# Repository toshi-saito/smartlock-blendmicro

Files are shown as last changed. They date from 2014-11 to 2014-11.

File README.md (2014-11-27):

# SmartLock by Blend Micro

"SmartLock" implementation for Blend Micro (Arduino Compatible Board)

## iOS Client
https://github.com/toshi-saito/smartlock-ios-client

## Schematic
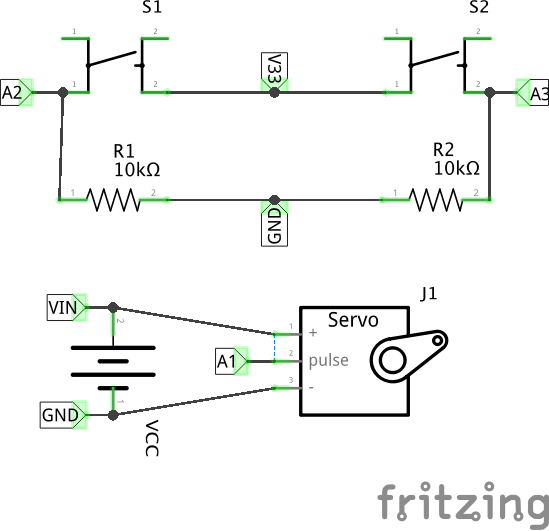
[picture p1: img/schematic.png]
回路図


## Finished product

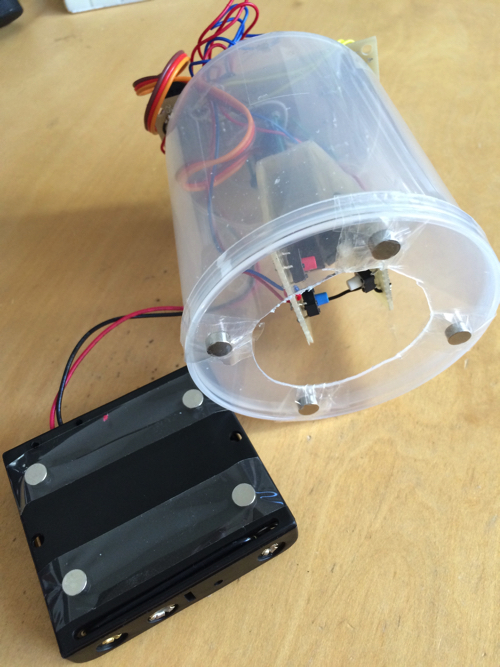
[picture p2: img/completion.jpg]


mounting:  
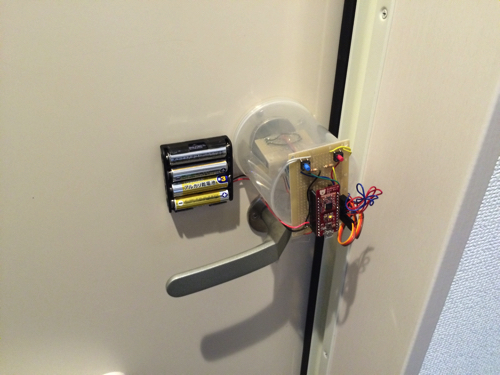
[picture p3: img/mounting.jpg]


front:  
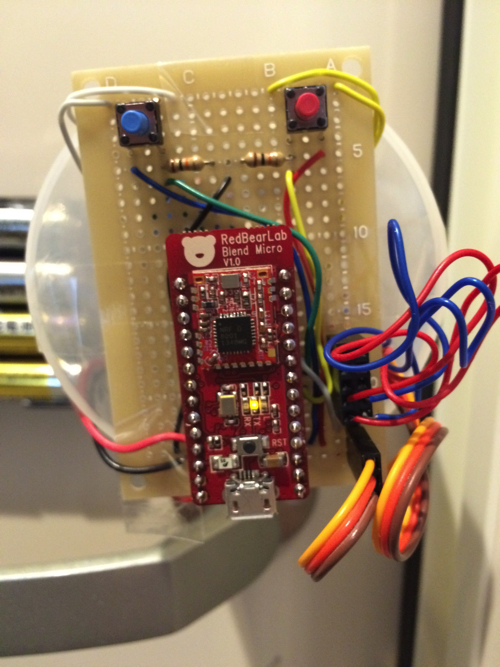
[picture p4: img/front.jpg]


side:  
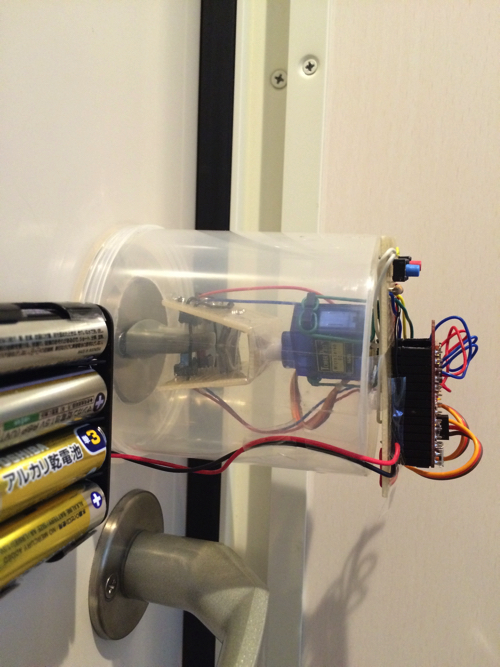
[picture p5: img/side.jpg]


main board side:  
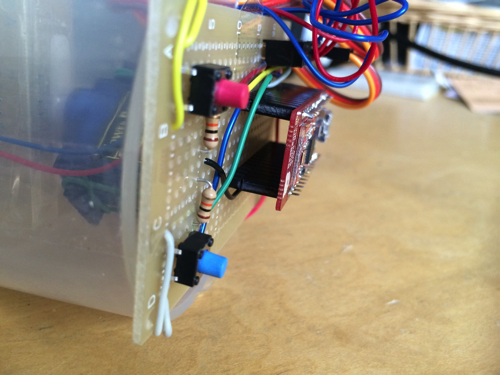
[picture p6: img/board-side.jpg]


thumbturn:  
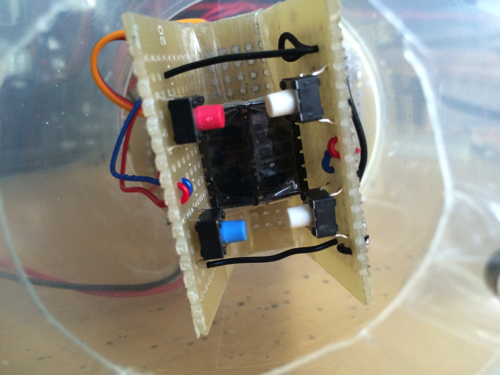
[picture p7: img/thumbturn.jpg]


## Videos
Arduino互換ボードBlendMicroでスマートロックを自作してみた。 (http://www.youtube.com/watch?v=r_P2eok-eCo)

Arduino互換ボードBlendMicroでスマートロックを自作してみた。その2 (http://www.youtube.com/watch?v=pR7_fCwM83g)

## Things to prepare
[Blend Micro](http://redbearlab.com/blendmicro/)  
[カーボン抵抗 carbon resistance 10kΩ ](http://akizukidenshi.com/catalog/g/gR-25103/) x 2  
[タクトスイッチ tact switch](http://akizukidenshi.com/catalog/g/gP-03647/) x 6  
[電池ボックス 単３×４本 4xAA battery box ](http://akizukidenshi.com/catalog/g/gP-02671/) x 1  
[ユニバーサル基板 universal board ](http://akizukidenshi.com/catalog/g/gP-03229/) x 2  
[耐熱電子ワイヤー Heat-resistant electronic wire](http://akizukidenshi.com/catalog/g/gP-06756/)  
[分割ロングピンソケット pin receptacle](http://akizukidenshi.com/catalog/g/gC-05779/)  
[ピンヘッダ pin header](http://akizukidenshi.com/catalog/g/gC-00167/)  
-[サーボモータ servo SG90](http://www.amazon.co.jp/gp/product/B00I9SYEKC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)  
-綿棒ケース swab container x 1 （ダイソーで。）  
-ネオジム磁石 neodymium magnets（ダイソーで。）  
-セロハンテープ cellophane tape (一番出番多い。)  

## Thumbturn Knob Create Guide
use universal board  
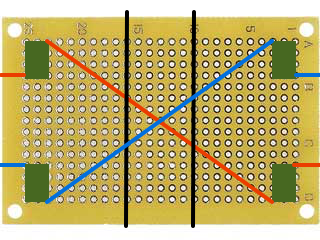
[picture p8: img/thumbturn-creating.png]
  
黒の線に沿ってユニバーサル基板をカットしてください。  
緑はタクトスイッチです。  
赤と青は耐熱電子ワイヤーの配線です。  
基板外に出ている線(4本)はサーボモータの導線程度の長さを確保してください。  
切り取った真ん中の細長い基板に、サーボに付属している軸に取り付ける部品をセロハンテープで固定します   。
セロハンテープで切り取った基板を貼り付けてコの字型に形成します。  
内側にピンソケットなどを半田付けして、固定すると良いです。  

## TODO
* 名前募集中。
* サーボの電源が常時ONなので、MOSFET挟んで、動作時のみONにしたほうが良さげ。
* ひらけゴマ方式なので、ペアリング時にパスフレーズを生成して、EEPROMに保存。

## Links

Blend Micro  
http://redbearlab.com/blendmicro/

Arduino  
http://www.arduino.cc/

frintzing  
http://fritzing.org/home/

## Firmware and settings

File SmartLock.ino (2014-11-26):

#include <SPI.h>
#include <boards.h>
#include <RBL_nRF8001.h>
#include <Servo.h>

#define SERVO_SIGNAL A1
#define UNLOCK_SW A2
#define LOCK_SW A3

#define UNLOCK_PHRASE "unlock"
#define LOCK_PHRASE "lock"
#define STATE_PHRASE "state"

Servo servo;
bool isOpen;

void setup() {
  ble_begin();
  Serial.begin(57600);
  pinMode(INPUT, LOCK_SW);
  pinMode(INPUT, UNLOCK_SW);
  touchServo(0);
  isOpen = false;
}

void loop() {
  if (!ble_connected()) {
    watchSwitchEvent();
    ble_do_events();
    return;
  }
  
  if (ble_available()) {
    char command[255];
    readCommand(command);
    if (0==strcmp(command, UNLOCK_PHRASE)) {
      doUnlock();
    } else if (0==strcmp(command, LOCK_PHRASE)) {
      doLock();
    } else if (0==strcmp(command, STATE_PHRASE)) {
      sendStatus();
    }
  }
  
  watchSwitchEvent();
  
  ble_do_events();
}

void readCommand(char* chr) {
  int i = 0;
  chr[0] = '\0';
  while (ble_available()) {
    chr[i] = ble_read();
    i++;
  }
  chr[i] = '\0';
  Serial.println(chr);
}

void watchSwitchEvent() {
  if (digitalRead(LOCK_SW) == HIGH) {
    doLock();
  } else if (digitalRead(UNLOCK_SW) == HIGH) {
    doUnlock();
  }
}

void doLock() {
  touchServo(0);
  isOpen = false;
  sendStatus();
}

void doUnlock() {
  touchServo(90);
  isOpen = true;
  sendStatus();
}

void delay_with_ble(int n) {
  for (int i = 0; i < n/10; i++) {
    delay(10);
    ble_do_events();
  }
}

void touchServo(int degree) {
  servo.attach(SERVO_SIGNAL);
  delay_with_ble(100);
  servo.write(degree);
  // サーボが動き終わるまで適当な時間待つ。
  delay_with_ble(600);
  servo.detach();
  delay_with_ble(200);
}

void sendStatus() {
  if (isOpen) {
    byte buf[] = {'O', '\0'};
    ble_write_string(buf, 2);
  } else {
    byte buf[] = {'X', '\0'};
    ble_write_string(buf, 2);
  }
}

static byte buf_len = 0;
void ble_write_string(byte *bytes, uint8_t len) {
  if (buf_len + len > 20) {
    for (int j = 0; j < 15000; j++) {
      ble_do_events();
    }
    buf_len = 0;
  }
  
  for (int j = 0; j < len; j++) {
    ble_write(bytes[j]);
    buf_len++;
  }
    
  if (buf_len == 20) {
    for (int j = 0; j < 15000; j++) {
      ble_do_events();
    }
    buf_len = 0;
  }  
}
